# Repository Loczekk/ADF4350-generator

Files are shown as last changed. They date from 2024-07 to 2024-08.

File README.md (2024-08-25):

<!-- TABLE OF CONTENTS -->

<details>
  <summary>Table of Contents</summary>
  <ol>
    <li><a href="#about-the-project">About The Project</a></li>
    <li><a href="#introduction">Introduction</a></li>
    <li><a href="#final-parameters">Final parameters</a></li>
    <li><a href="#block-diagram">Block diagram</a></li>
    <li><a href="#pcb-design">PCB design</a></li>
    <li><a href="#cover-design">Cover design</a></li>
    <li><a href="#measurements">Measurements</a></li>
  </ol>
</details>

<!-- ABOUT THE PROJECT -->
## About The Project

done

My design of an RF generator based on the ADF4350, used as a heterodyne signal in my radiotelescope.

<p align="right">(<a href="#readme-top">back to top</a>)</p>

<!-- GETTING STARTED -->
## Introduction

The assumption of the project was to create a small and simple RF generator, with good parameters and high stability. At the very beginning, the generator design based on separate components was eliminated, i.e. separate VCO, PLL, dividers, multiplexers and final stages. Such a design can provide the best stability and noise parameters and be freely and easily modified, but it requires complex design and time-consuming tests. In this straightforward project, reliance is placed on the use of a Wideband Synthesizer with Integrated VCO, which will provide good parameters and in one "silicon" unit will have integrated basic components of the RF generator and the ability to program the output frequencies. I decided on the ADF4350 because of the parameters that were in line with the assumptions. What's more, the free samples I received from the manufacturer were an additional advantage.

<p align="right">(<a href="#readme-top">back to top</a>)</p>

## Final parameters

Dimensions: 

PCB: 51mm x 46mm,

Cover:  58mm x 53mm x 27mm

•	Power supply: +5V, >200mA

•	Output power: 9-15dBm

•	Frequency range: 550-4400MHz

•	4 programmable frequency values

•	SMA connectors

•	Frequency stability: +/- 350 Hz (depends on the frequency)

•	Phase noice: (-85) – (-105) dBc/Hz

•	Harmonics: -4dB (worst case)

<p align="right">(<a href="#readme-top">back to top</a>)</p>

## Block diagram

Adf4350_RF_gen drawio

<p align="right">(<a href="#readme-top">back to top</a>)</p>

## PCB design

layers

To maintain the intended dimensions and improve RF properties (thinner 50 Ohm paths), the PCB is 4-layer.
The design was based on a schematic diagram provided by the manufacturer in the catalog note. To ensure high stability, each voltage pin has its own stabilizer and copper plates. The mass is common, only under the quartz it is cut off. For easier assembly (soldering the ground pad), there is an enlarged hole in the PCB. The mounting holes were placed in convenient places due to the planned use of a 3D printed casing, designed for PCB. An exposed copper ring is used to mount the RF shielding.

<p align="right">(<a href="#readme-top">back to top</a>)</p>

## Cover design

rend

The case was designed in Fusion360 using a PCB model generated in KiCad. 2 screws were used to screw the PCB to the lower part of the cover, another two were used to connect both parts of the case. There are also holes for 2 LEDs, a DC power and SMA connectors. To improve the appearance, the outer layers of the housing were printed using the Hilbert curve on an Ender 3 printer.

<p align="right">(<a href="#readme-top">back to top</a>)</p>

## Measurements

Measurements were made according to the connections shown in the diagram below. For this purpose, a Rohde&Schwarz FSV spectrum analyzer and a pendulum frequency counter, model CNT-104S, were used. The generator was powered by a laboratory power supply. All devices were turned on for at least 1 hour before the measurement to stabilize the temperature and achieve stable measurement conditions. The frequency stability measurement took 4 hours, after which the generator was switched to the input of the spectrum analyzer and after waiting 30 minutes, measurements of harmonics, signal power and phase noise were made. The procedure was repeated for 3 frequencies from different operating ranges of the ADF4350 synthesizer: 600MHz, 1380MHz and 2400MHz.

uklad_pomiarowy drawio

Measurement results for the 600MHz frequency:

•	Output frequency (exact): 600001200 Hz

•	Frequency stability: +/-150Hz

•	Power consumption: 0,79mW

•	Output power: 14,34 dBm

•	Phase noice (10kHz): -103,1dBc/Hz

•	Harmonics: 2nd: -9dB, 3rd: -20dB, 4th: -25dB

600MHz

Measurement results for the 1380MHz frequency:

•	Output frequency (exact): 1380002470 Hz

•	Frequency stability: +/-300 Hz

•	Power consumption: 0,73 mW

•	Output power: 9,1 dBm

•	Phase noice (10 kHz): -90,25 dBc/Hz

•	Harmonics: 2nd: -16dB, 3rd: -4dB, 4th: -25dB

1380MHz

Measurement results for the 2400MHz frequency:

•	Output frequency (exact): 2400004910 Hz

•	Frequency stability: +/-350Hz

•	Power consumption: 0,72 mW 

•	Output power: 11,45 dBm

•	Phase noice (10kHz): -87,57 dBc/Hz

•	Harmonics: 2nd: -15dB, 3rd: out of range FSV

<p align="right">(<a href="#readme-top">back to top</a>)</p>
2400MHz

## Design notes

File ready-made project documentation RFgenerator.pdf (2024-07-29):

# Small and very stable RF power generator

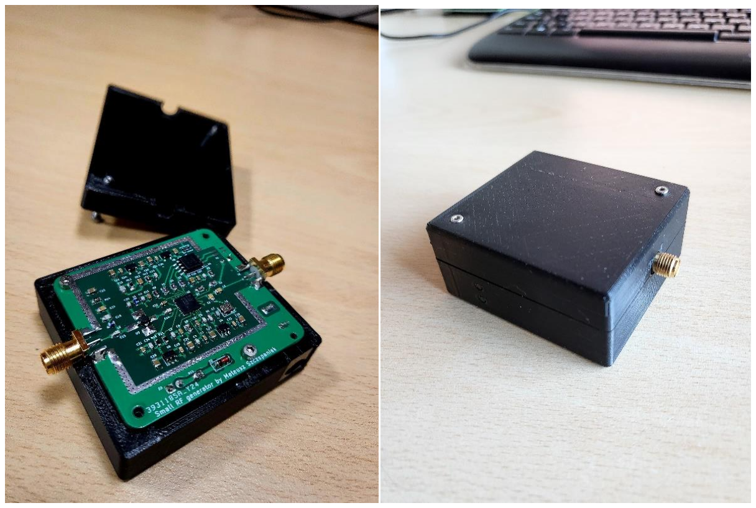
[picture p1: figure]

## Realisation: Mateusz Szczepaniak Kraków 27.12.2023

## Content Page

# 1. Introduction

The assumption of the project was to create a small and simple RF generator, with good parameters and high stability. At the very beginning, the generator design based on separate components was eliminated, i.e. separate VCO, PLL, dividers, multiplexers and final stages. Such a design can provide the best stability and noise parameters and be freely and easily modified, but it requires complex design and time-consuming tests. In this straightforward project, reliance is placed on the use of a Wideband Synthesizer with Integrated VCO, which will provide good parameters and in one "silicon" unit will have integrated basic components of the RF generator and the ability to program the output frequencies. Integrated circuits from two manufacturers met the requirements: ADF4350 from Analog Devices and LMX2581 from Texas Instruments. Both solutions have very similar parameters, features and functions, the basic ones are summarized in the table below:

Parameters | ADF4350 | LMX2581
Output frequencies | 137.5 MHz to 4400 MHz | 50 to 3760 MHz
Power consuption | 130mA | 178mA
VCO range | 2,2GHz – 4,4GHz | 1,88GHz – 3,76GHz
Phase noice for 10kHz offset
2,2GHz | -89dBc/Hz | -85,4dBc/Hz
3,3GHz | -86dBc/Hz | -79dBc/Hz

ADF4350 covers the entire assumed frequency range, has better parameters, but is 30% more expensive than LMX2581. The ADF circuit was ordered from free samples on the manufacturer's website, which is another advantage.

An Attiny microcontroller will be used to program the output frequencies due to its simplicity, small size and lack of additional peripherals.

To ensure adequate output power, the PCB will be equipped with an output amplifier, and circuits sensitive to power supply noise will be powered by separate stabilizers to improve parameters.

# 2. Project scope

- Choosing the optimal solution
- Designing a schematic diagram
- Designing a PCB
- Designing a 3D printed housing
- Installation
- Tests and measures

# 3. Technical Parameters

- Dimensions:
PCB: 51mm x 46mm,
Cover: 58mm x 53mm x 27mm
- Power supply: +5V, >200mA
- Output power: 9-15dBm
- Frequency range: 550-4400MHz
- 4 programmable frequency values
- SMA connectors
- Frequency stability: +/- 350 Hz (depends on the frequency)
- Phase noice: (-85) – (-105) dBc/Hz
- Harmonics: -4dB (worst case)

# 4. Block diagram

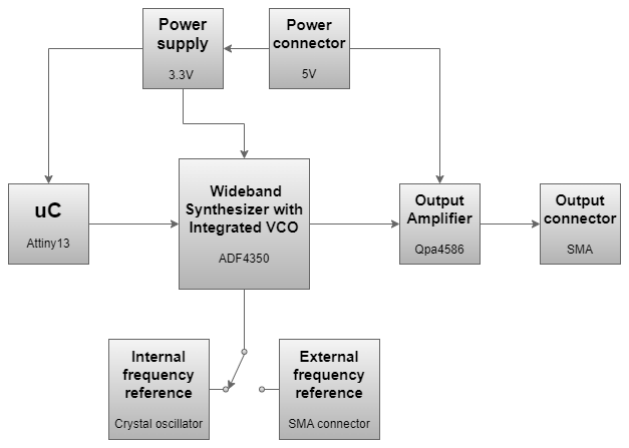
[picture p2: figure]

# 5. Scheme

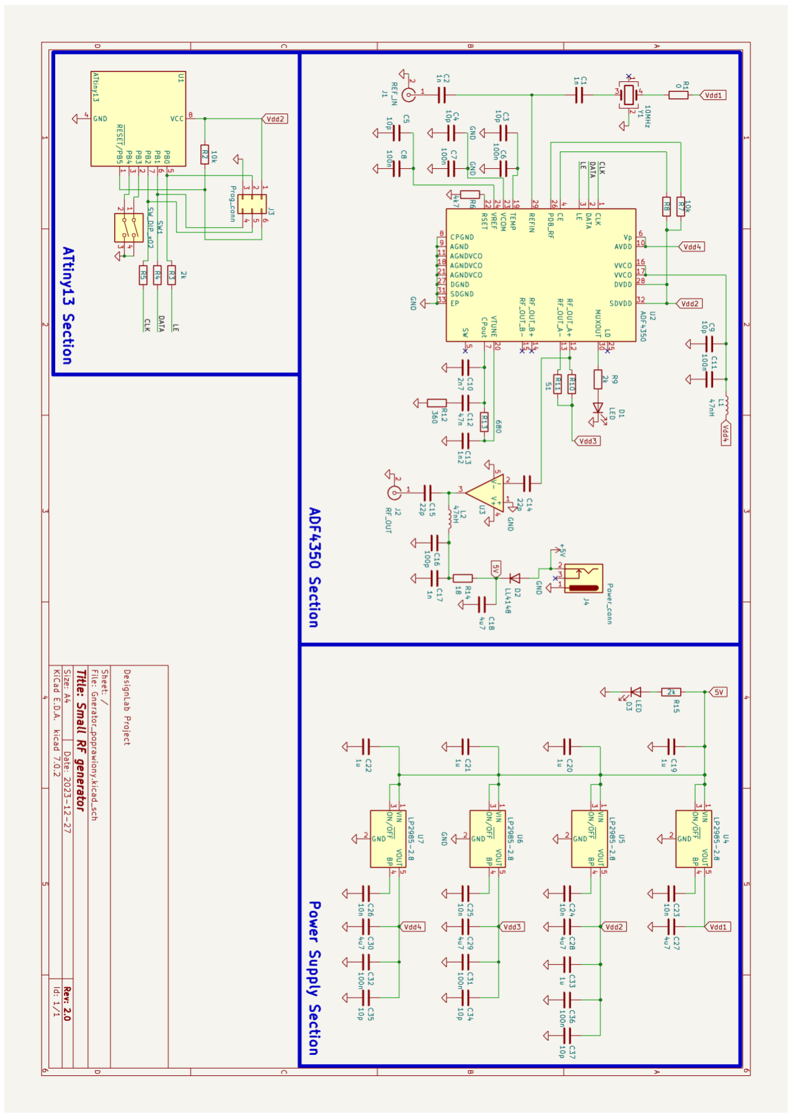
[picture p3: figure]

# 6. PCB design

To maintain the intended dimensions and improve RF properties (thinner 50 Ohm paths), the PCB is 4-layer. The design was based on a schematic diagram provided by the manufacturer in the catalog note. To ensure high stability, each voltage pin has its own stabilizer and copper plates. The mass is common, only under the quartz it is cut off. For easier assembly (soldering the ground pad), there is an enlarged hole in the PCB. The mounting holes were placed in convenient places due to the planned use of a 3D printed casing, designed for PCB. An exposed copper ring is used to mount the RF shielding.

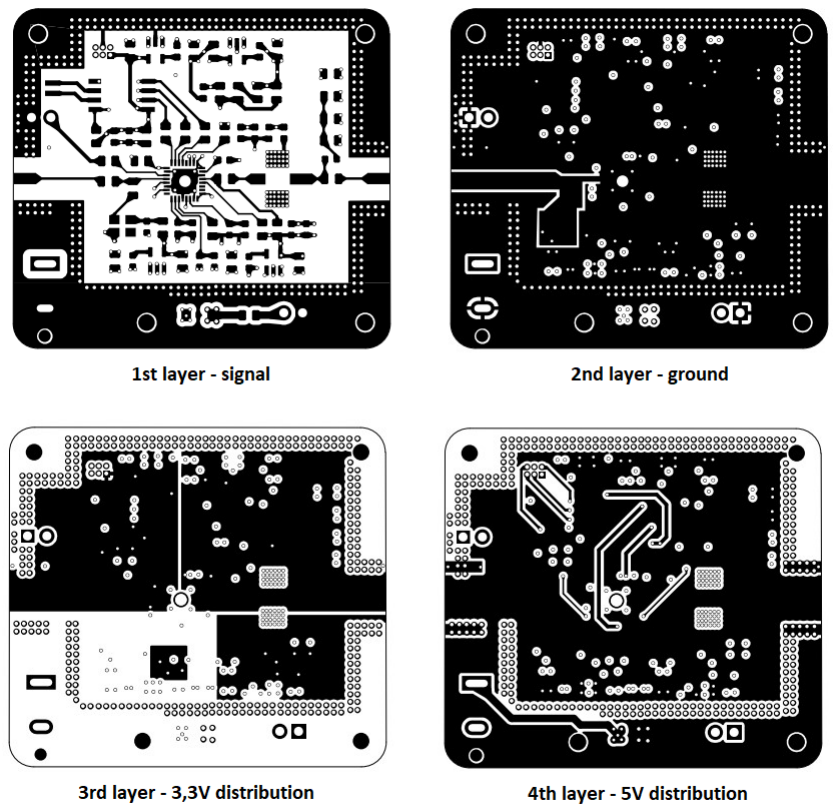
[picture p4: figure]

Pic.1. Layers stack

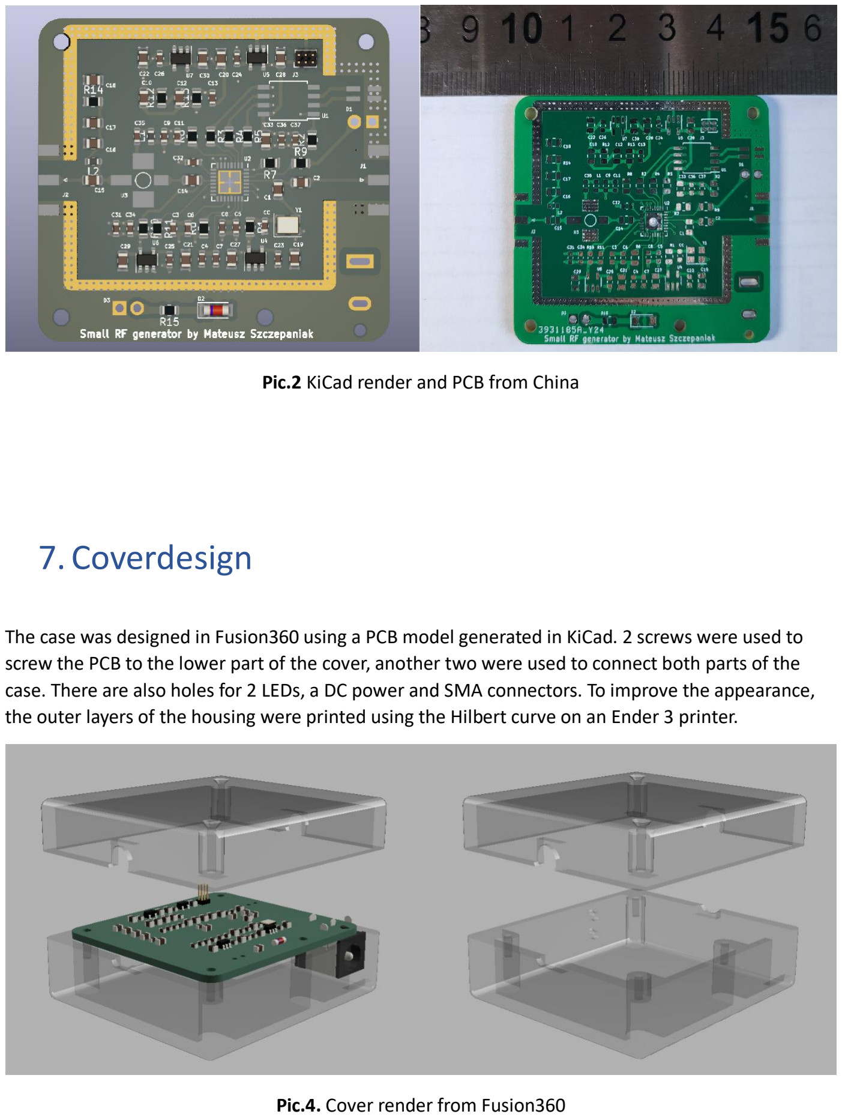
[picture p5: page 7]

Pic.2 KiCad render and PCB from China

# 7. Coverdesign

The case was designed in Fusion360 using a PCB model generated in KiCad. 2 screws were used to screw the PCB to the lower part of the cover, another two were used to connect both parts of the case. There are also holes for 2 LEDs, a DC power and SMA connectors. To improve the appearance, the outer layers of the housing were printed using the Hilbert curve on an Ender 3 printer.

Pic.4. Cover render from Fusion360

# 8. Assembly

After the boards arrived from China, the soldering stage began, starting from the smallest elements, ending with THT assembly. After checking the correct operation: no short circuits, loading the program and the PLL "catching" the frequency, the RF shielding was installed and the cover was assembled.

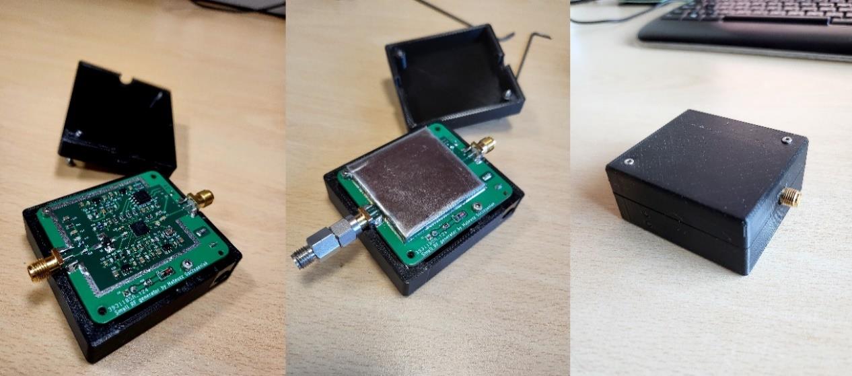
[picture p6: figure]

Pic.5. Assembled device

# 9. Tests and measurements

Measurements were made according to the connections shown in the diagram below. For this purpose, a Rohde&Schwarz FSV spectrum analyzer and a pendulum frequency counter, model CNT-104S, were used. The generator was powered by a laboratory power supply. All devices were turned on for at least 1 hour before the measurement to stabilize the temperature and achieve stable measurement conditions. The frequency stability measurement took 4 hours, after which the generator was switched to the input of the spectrum analyzer and after waiting 30 minutes, measurements of harmonics, signal power and phase noise were made. The procedure was repeated for 3 frequencies from different operating ranges of the ADF4350 synthesizer: 600MHz, 1380MHz and 2400MHz.

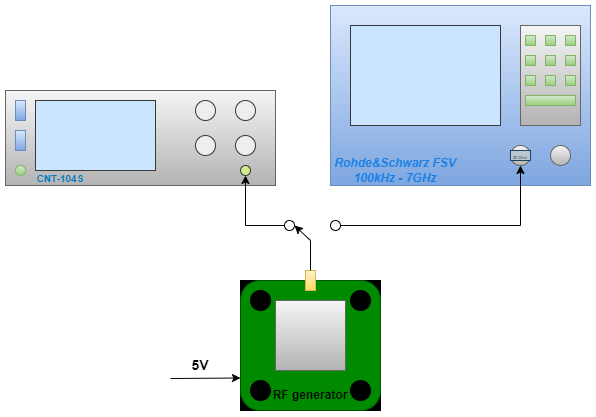
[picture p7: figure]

Pic.6. Measurement scheme

Measurement results for the 600MHz frequency:
- Output frequency (exact): 600001200 Hz
- Frequency stability: +/-150Hz
- Power consumption: 0,79mW
- Output power: 14,34 dBm
- Phase noice (10kHz): -103,1dBc/Hz
- Harmonics: 2nd: -9dB, 3rd: -20dB, 4th: -25dB

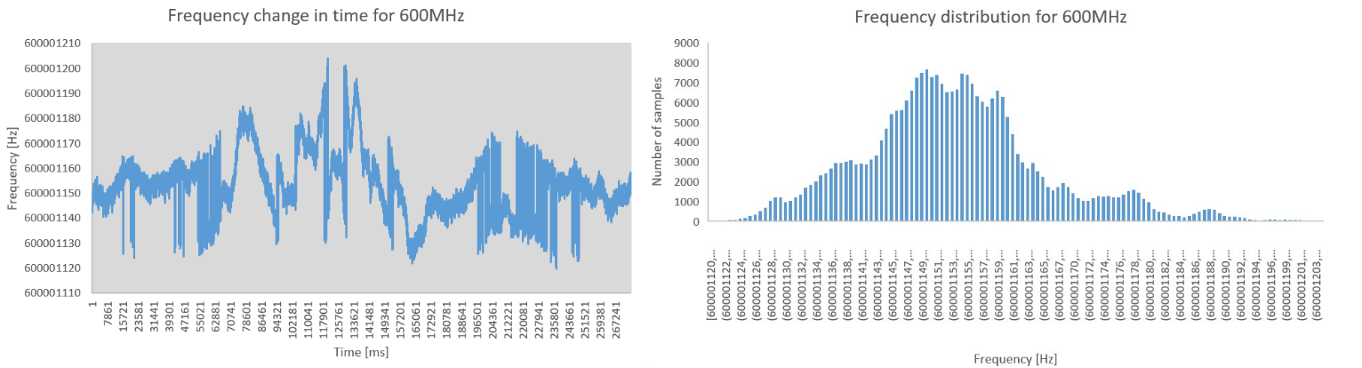
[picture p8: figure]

Pic.7. 600MHz measurement charts

Measurement results for the 1380MHz frequency:
- Output frequency (exact): 1380002470 Hz
- Frequency stability: +/-300 Hz
- Power consumption: 0,73 mW
- Output power: 9,1 dBm
- Phase noice (10 kHz): -90,25 dBc/Hz
- Harmonics: 2nd: -16dB, 3rd: -4dB, 4th: -25dB

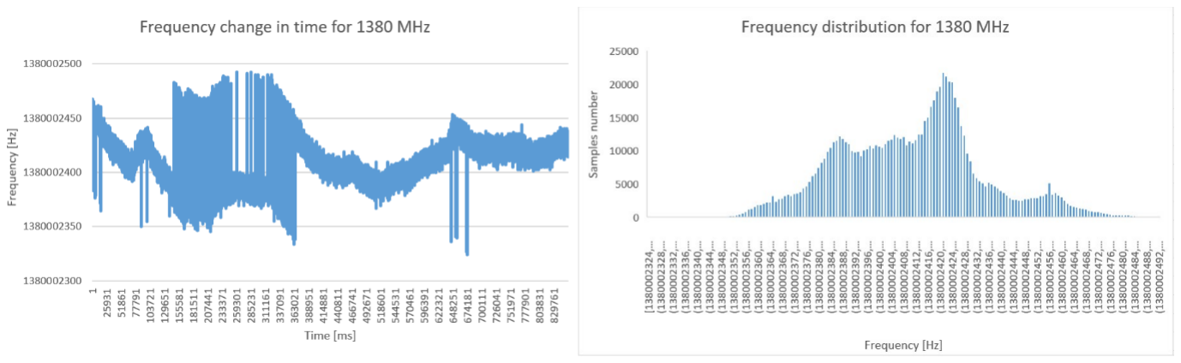
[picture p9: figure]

Pic.8. 1380MHz measurement charts

Measurement results for the 2400MHz frequency:
- Output frequency (exact): 2400004910 Hz
- Frequency stability: +/-350Hz
- Power consumption: 0,72 mW
- Output power: 11,45 dBm
- Phase noice (10kHz): -87,57 dBc/Hz
- Harmonics: 2nd: -15dB, 3rd: out of range FSV

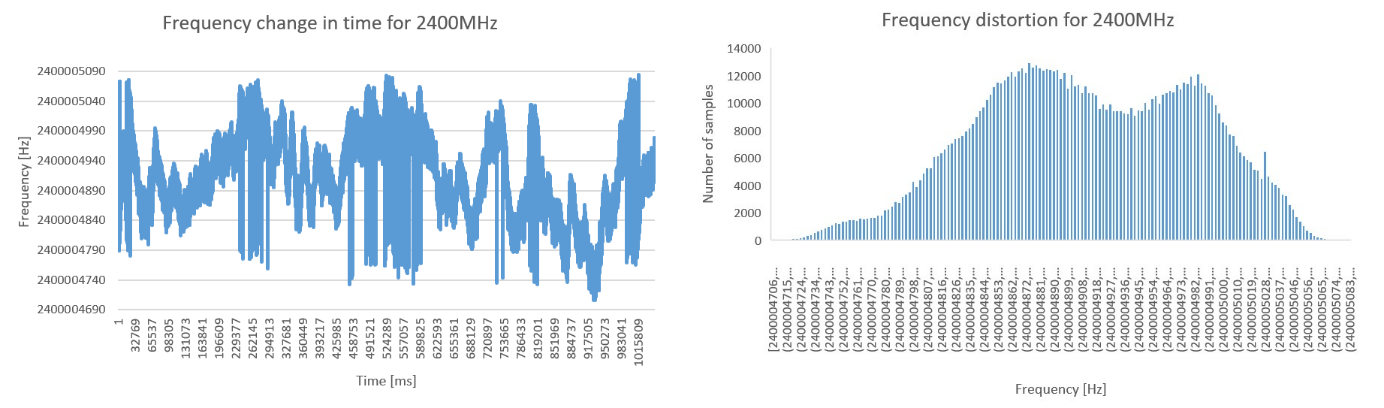
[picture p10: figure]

Pic.7. 2400MHz measurement charts

| Frequency | Stability | Power consumtion | Output power | Phase noise | Harmonics
550-1100 MHZ | 600001200 Hz | +/-150Hz | 0,79mW | 14,34 dBm | -103,1 dBc/Hz | 2nd: -9dB, 3rd: -20dB, 4th: -25dB
1100-2200 MHz | 1380002470 Hz | +/-300 Hz | 0,73mW | 9,1 dBm | -90,25 dBc/Hz | 2nd: -16dB, 3rd: -4dB, 4th: -25dB
2200-4400 MHZ | 2400004910 Hz | +/-350Hz | 0,72mW | 11,45 dBm | -87,57 dBc/Hz | 2nd: -15dB

# 10. Bill of materials

Part | Package | Quantity | Value
D2 | D_MiniMELF | 1 | LL4148
C20,C22,C21,C19,C33 | C0805 | 5 | 1uF
C27,C18,C28,C29,C30 | C0805 | 5 | 4u7F
R6 | R0805 | 1 | 4k7F
C5,C35,C34,C37,C9,C4,C3 | C0603 | 7 | 10pF
R7,R8,R2 | R0805 | 3 | 10kΩ
C16 | C0805 | 1 | 100pF
R12 | R0805 | 1 | 360Ω
R11,R10 | R0805 | 2 | 51Ω
R5,R3,R4,R9,R15 | R0805 | 5 | 2kΩ
C14,C15 | C0805 | 2 | 22pF
C17,C1,C2 | C0805 | 3 | 1nF
L1,L2 | L0603 | 2 | 47nH
C25,C26,C23,C24 | C0603 | 4 | 10nF
R13 | R0805 | 1 | 680Ω
R14 | R0805 | 1 | 18Ω
U2 | LFCSP-32-1EP | 1 | ADF4350
C31,C6,C8,C32,C11,C36,C7 | C0603 | 7 | 100nF
R1 | R0805 | 1 | 0
U4,U7,U5,U6 | SOT-23-5 | 4 | LP2985
C10 | C0805 | 1 | 2n7F
CC | C0603 | 1
C13 | C0603 | 1 | 1n2F
J2 | SMA_AmphenolEdgeMount | 1 | RF_OUT
C12 | C0805 | 1 | 47nF
U1 | SOIC-8W | 1 | ATtiny13
Y1 | Crystal_SMD_3225-4Pin | 1 | 10MHz
D1,D3 | D_DO-15_P2.54mm | 2 | LED
U3 | TO-50-4 | 1
J1 | SMA_AmphenolEdgeMount | 1 | REF_IN
J3 | PinHeader_2x03_P1.00mm | 1 | Prog_conn
J4 | BarrelJack | 1 | Power_conn

# 11. Literature

1. VHFdesign: LO PLL ADF4350 project: https://vhfdesign.com/plls/lo-pll-adf4350.html
2. Zdzisław Bieńkowski „Poradnik ultrakrólkofalowca” 1988.
3. https://www.analog.com/media/en/technical-documentation/data-sheets/adf4350.pdf

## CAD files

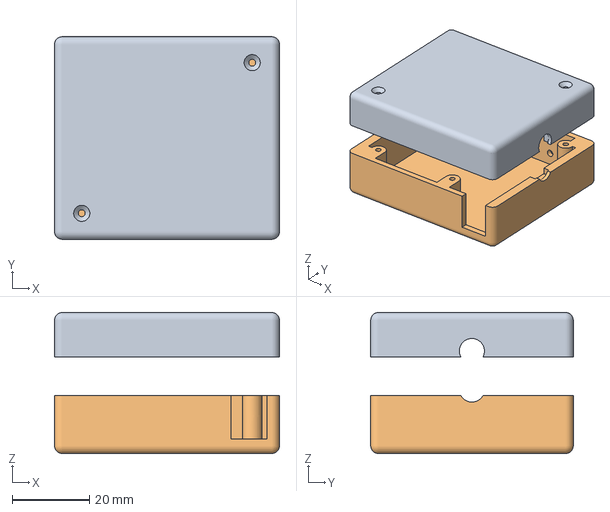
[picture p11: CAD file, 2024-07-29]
generator_housing.3mf
58.4 x 52.6 x 36.6 mm
Bryła13
Bryła6

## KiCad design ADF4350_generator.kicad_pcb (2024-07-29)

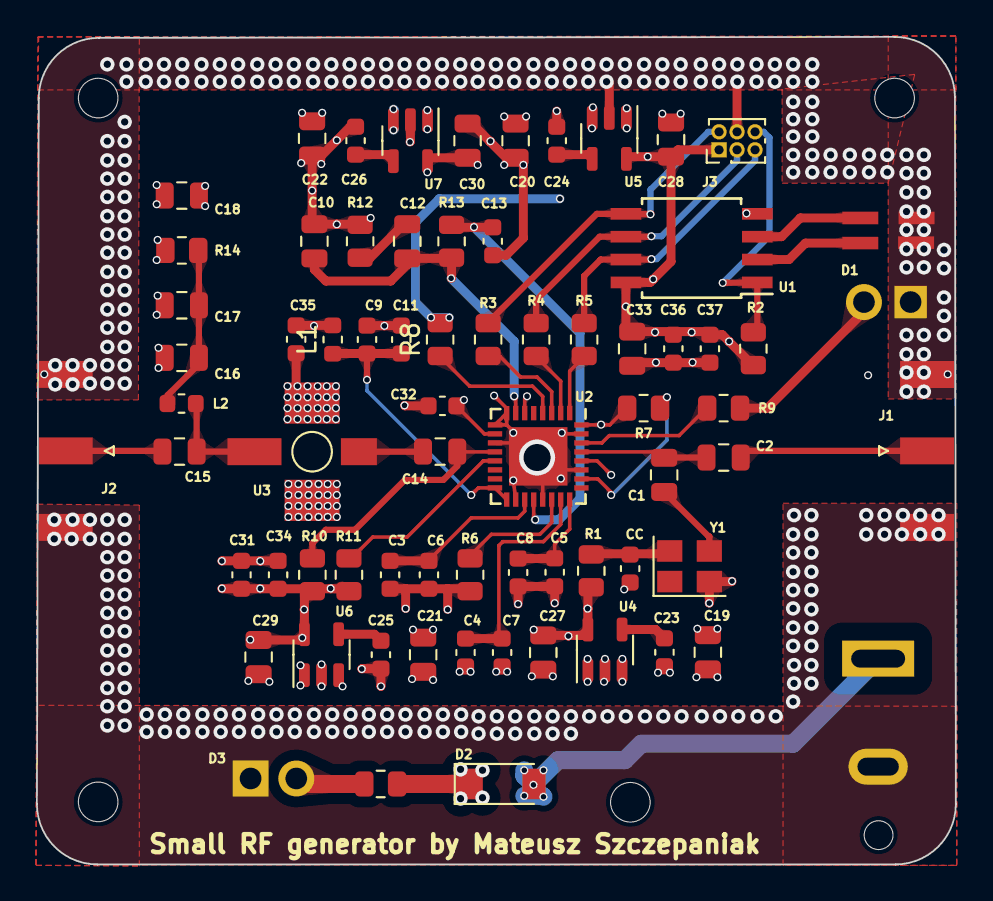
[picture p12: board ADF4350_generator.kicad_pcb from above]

Board: 4 copper layers, 51.1 x 46.0 mm, 71 parts (1 on the bottom side), 43 nets.

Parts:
C1, C2, C17: 1n; C_0805_2012Metric
C3, C4, C5, C9, C34, C35, C37: 10p; C_0603_1608Metric
C6, C7, C8, C11, C31, C32, C36: 100n; C_0603_1608Metric
C10: 2n7; C_0805_2012Metric
C12: 47n; C_0805_2012Metric
C13: 1n2; C_0603_1608Metric
C14, C15: 22p; C_0805_2012Metric
C16: 100p; C_0805_2012Metric
C18, C27, C28, C29, C30: 4u7; C_0805_2012Metric
C19, C20, C21, C22, C33: 1u; C_0805_2012Metric
C23, C24, C25, C26: 10n; C_0603_1608Metric
CC: C_0603_1608Metric
D1, D3: LED; D_DO-15_P2.54mm_Vertical_AnodeUp
D2: LL4148; D_MiniMELF
J1: REF_IN; SMA_Amphenol_132289_EdgeMount
J2: RF_OUT; SMA_Amphenol_132289_EdgeMount
J3: Prog_conn; PinHeader_2x03_P1.00mm_Vertical
J4: Power_conn; BarrelJack_CUI_PJ-063AH_Horizontal
L1, L2: 47nH; L_0603_1608Metric
R1: 0; R_0805_2012Metric
R2, R7, R8: 10k; R_0805_2012Metric
R3, R4, R5, R9, R15: 2k; R_0805_2012Metric
R6: 4k7; R_0805_2012Metric
R10, R11: 51; R_0805_2012Metric
R12: 360; R_0805_2012Metric
R13: 680; R_0805_2012Metric
R14: 18; R_0805_2012Metric
SW1: SW_DIP_x02; PinHeader_2x02_P2.54mm_Vertical_SMD
U1: ATtiny13; SOIC-8W_5.3x5.3mm_P1.27mm
U2: ADF4350; LFCSP-32-1EP_5x5mm_P0.5mm_EP3.25x3.25mm
U3: type="X" model="OPAMP" lib=""; TO-50-4_ShortPad-NoHole_Housing
U4, U5, U6, U7: LP2985-2.8; SOT-23-5
Y1: 10MHz; Crystal_SMD_3225-4Pin_3.2x2.5mm

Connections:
5V: C18.1, C19.1, C20.1, C21.1, C22.1, D2.1 (K), R14.1, R15.1, U4.1 (VIN), U4.3 (ON/~OFF), U5.1 (VIN), U5.3 (ON/~OFF), U6.1 (VIN), U6.3 (ON/~OFF), U7.1 (VIN), U7.3 (ON/~OFF)
+5V: D2.2 (A), J4.2
/CLK: R5.2, U2.1 (CLK)
/DATA: R4.2, U2.2 (DATA)
/LE: R3.2, U2.3 (LE)
GND: C3.2, C4.2, C5.2, C6.2, C7.2, C8.2, C9.2, C10.1, C11.2, C13.1, C16.2, C17.2, C18.2, C19.2, C20.2, C21.2, C22.2, C23.2, C24.2, C25.2, C26.2, C27.2, C28.2, C29.2, C30.2, C31.2, C32.2, C33.2, C34.2, C35.2, C36.2, C37.2, CC.1, D1.1 (K), D3.1 (K), J1.2 (Ext), J2.2 (Ext), J3.3, J4.1, R6.1, R12.2, SW1.3, SW1.4, U1.4 (GND), U2.8 (CPGND), U2.9 (AGND), U2.11 (AGNDVCO), U2.18 (AGNDVCO), U2.21 (AGNDVCO), U2.27 (DGND), U2.31 (SDGND), U2.33 (EP), U3.1 (+), U3.4 (V+), U4.2 (GND), U5.2 (GND), U6.2 (GND), U7.2 (GND), Y1.2
unnamed: C1.2, Y1.3
unnamed: C9.1, C11.1, L1.1, U2.16 (VVCO), U2.17 (VVCO)
unnamed: C12.1, R12.1
unnamed: C15.1, L2.1, U3.3
unnamed: C16.1, C17.1, L2.2, R14.2
unnamed: D1.2 (A), R9.2
unnamed: D3.2 (A), R15.2
unnamed: C2.1, J1.1 (In)
unnamed: C15.2, J2.1 (In)
unnamed: J3.2, R3.1, U1.5 (PB0)
unnamed: J3.4, R4.1, U1.6 (PB1)
unnamed: J3.5, R5.1, U1.7 (PB2)
unnamed: J3.6, R2.2, U1.1 (~RESET/PB5)
unnamed: CC.2, R1.1, Y1.4 (1)
unnamed: SW1.1, U1.2 (PB3)
unnamed: SW1.2, U1.3 (PB4)
unnamed: R8.1, U2.4 (CE)
unnamed: C10.2, C12.2, R13.1, U2.7 (CPout)
unnamed: R9.1, U2.30 (MUXOUT)
unnamed: R7.1, U2.26 (PDB_RF)
unnamed: C1.1, C2.2, U2.29 (REFIN)
unnamed: C14.1, R10.1, U2.12 (RF_OUT_A+)
unnamed: R11.1, U2.13 (RF_OUT_A-)
unnamed: R6.2, U2.22 (RSET)
unnamed: C3.1, C6.1, U2.19 (TEMP)
unnamed: C4.1, C7.1, U2.23 (VCOM)
unnamed: C5.1, C8.1, U2.24 (VREF)
unnamed: C13.2, R13.2, U2.20 (VTUNE)
unnamed: C14.2, U3.2 (-)
unnamed: C23.1, U4.4 (BP)
unnamed: C24.1, U5.4 (BP)
unnamed: C25.1, U6.4 (BP)
unnamed: C26.1, U7.4 (BP)
Vdd1: C27.1, R1.2, U4.5 (VOUT)
Vdd2: C28.1, C33.1, C36.1, C37.1, J3.1, R2.1, R7.2, R8.2, U1.8 (VCC), U2.28 (DVDD), U2.32 (SDVDD), U5.5 (VOUT)
Vdd3: C29.1, C31.1, C34.1, R10.2, R11.2, U6.5 (VOUT)
Vdd4: C30.1, C32.1, C35.1, L1.2, U2.6 (Vp), U2.10 (AVDD), U7.5 (VOUT)

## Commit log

2024-07-29 KiCad files and stl of housing
    [ADF4350_generator.kicad_pcb, ADF4350_generator.kicad_sch, generator_housing.3mf]
2024-07-29 Create Gerbers
2024-07-29 add gerbers
    [ADF4350_generator-B_Cu.gbr, ADF4350_generator-B_Mask.gbr, ADF4350_generator-B_Paste.gbr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]
